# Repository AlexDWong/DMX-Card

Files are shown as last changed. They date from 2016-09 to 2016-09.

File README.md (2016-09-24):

# DMX-Card

Front

## Description
The DMX-Card is a small breakout board that allows developers to quickly add a UART-to-DMX (RS-485) circuit to their designs. It has been designed to cut down on the time spent constructing isolated DMX-512 circuits for prototype designs. The circuit is fully isolated and protected against ESD, and can be easily configured with a 3-pin XLR, 5-pin XLR, or 0.100" connector of the user's choice.

## Updates
**9/24/2016:** Board version 1.1; see directory for changes

**9/22/2016:** Board version 1.0 proven

## Features
* +5V input with polarity and over-current protection
* Full power and data isolation
  * Isolated DC-DC converter (1.5kVDC)
  * Isolated I/O via optocoupler (2.5kVDC)
  * ESD protection on all data inputs and outputs (including DMX)
* Full DMX compliance*
  * ANSI E1.20-2006 RDM compliant circuit, including correct biasing resistors (562/133/562)
  * 10MBd optocouplers
* User-selectable connectors:
  * Output: 
    * Neutrik NC3FAH (3-pin XLR)
    * Neutrik NC5FAH (5-pin XLR)
    * 0.100" PTH connectors (headers, screw terminal blocks, etc.)
  * Input:
    * 0.100" PTH connectors (headers, screw terminal blocks, etc.)

## Physical
* Board Dimensions: 0.95" x 1.90" (24.13mm x 48.26mm) (Actual dimensions will vary depending on the type of output connector installed)
* Board Thickness: 1.6mm
* Input Power: +5VDC, 60mA (nominal)
* Input Connections: +5V, GND, RX, TX, RX/TX Select
* Output: Isolated RS-485/DMX-512 (GND-ISO, D-, D+)
* Mounting: 4x 0.125" holes, located at edges of board

**circuit is constructed to ANSI E1.20; RDM must be correctly implemented on controller for full compliance*

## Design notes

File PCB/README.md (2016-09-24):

# PCB Files

This director contains all the files needed to modify the design of the DMX-Card. Revisions are separated into sub-directories, each of which contain the following files:

* Eagle `.BRD` and `.SCH` files (generated in Eagle 7.6.0)
* Board and schematic `.PNG` files for ease-of-access
* Gerber files
* Bill of Materials

Please note the following:
* All Eagle files have been checked for ERC and DRC errors using rule files provided by Elecrow. **If you choose to use a different fab house, please ensure that the boards meet their DRC requirements.**
* Similarly, the Gerber files have been generated using a CAM file provided by Elecrow; if you are planning to utilize a different fab house, you should either check to ensure they can accept the Gerber files located in this repository or generate your own Gerber files from the Eagle board and schematic files.

## Versions
### Version 1.1
Resolved several issues with version 1.0:
* Mounting holes in V1.0 were placed close to the edge of the board, which resulted in a high probability of edge breakage when depanelizing the boards. As a result, mounting holes have been reworked for greater clearance; note that some holes may be inaccessible depending on the connector choice.
* Input header moved away from the edge of the board to improve screw terminal block support.
* Electrolytic capacitor footprint removed; it was initially included in case additional decoupling was needed, but after testing the existing decoupling is satisfactory.
* Improved SMD component placement for easier hand-soldering. Namely, the two 10uF decoupling capacitors on the isolated side have been spaced further apart from each other, and the SM712 diode has been moved away from R9.
* Improved silkscreen layout to avoid conflicts with pads and vias.

### Version 1.0
Initial release. This version has been tested and is proven to work as described.

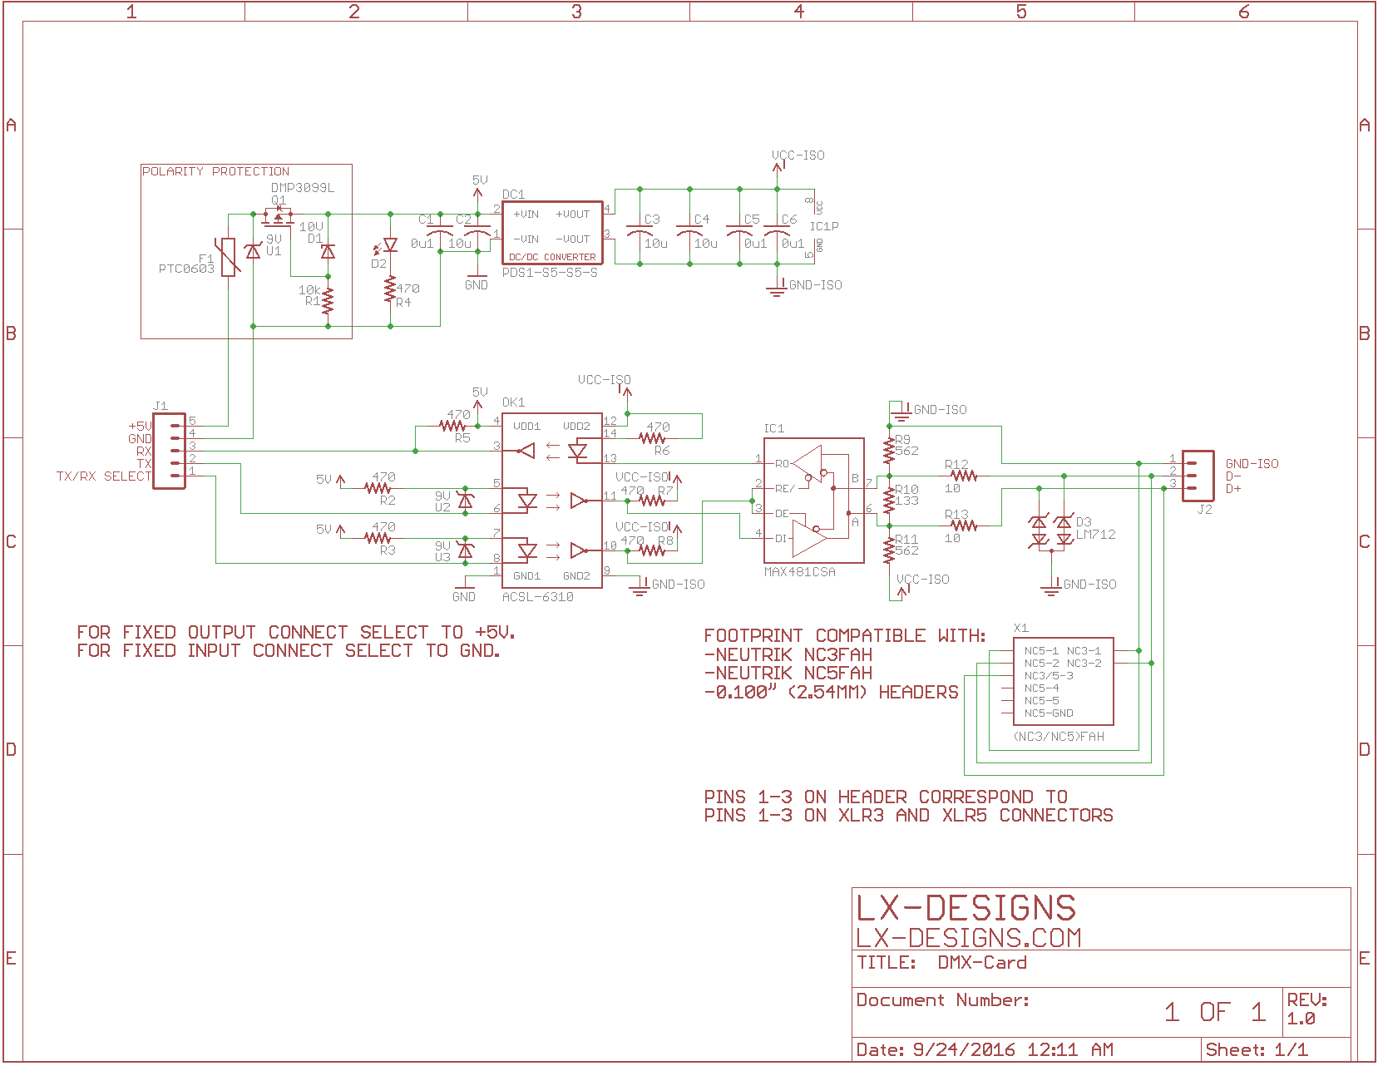
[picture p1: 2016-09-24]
PCB/V1.1/Schematic.png

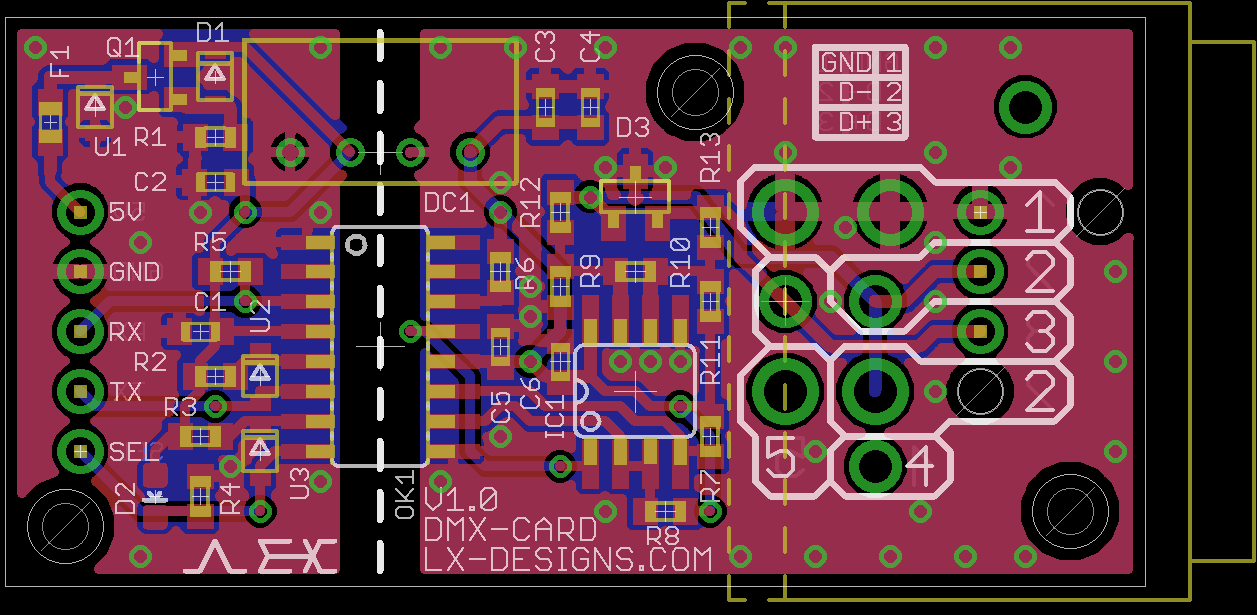
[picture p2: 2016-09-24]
PCB/V1.1/Board.png

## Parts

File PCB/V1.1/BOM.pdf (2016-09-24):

Item | Ref | Qty | Description | Mfg | Part Number
1 | C1, C5, C6 | 3 | Capacitor, 0.1uF, 16V, 10%, 0603 X5R | Murata Electronics | GRM188R61A106KE69D
2 | C2, C3, C4 | 3 | Capacitor, 10uF, 16V, 10%, 0603 X7R | Yageo | CC0603KRX7R7BB104
3 | D1, D4, D5 | 3 | TVS Diode, 1-channel Unidirectional, 9V, SOD323 | Toshiba | DF2S12FU,H3F
4 | D2 | 1 | Zener Diode,7.5V, 2%, 200mW, SOD-323 | ON Semiconductor | MM3Z7V5ST1G
5 | D3 | 1 | LED 2.1V/10mA, 0603 | Lite-On Inc. | LTST-C129GKT
6 | D6 | 1 | TVS Diode, 2-channel bidirectional, 12V/7V, SOT-23 | Littelfuse inc | SM712-02HTG
7 | DC1 | 1 | DC/DC Converter, Isolated, 5V, 1W, SIP-4 | CUI Inc | PDS1-S5-S5-S
8 | F1 | 1 | PTC Fuse, 9V, 200mA/450mA 0603 | Bel Fuse Inc | 0ZCM0020FF2G
9 | IC1 | 1 | Transceiver, RS485, Half-Duplex, 2.5Mbps, SOIC-8 | Maxim Integrated | MAX481CSA+
10 | OK1 | 1 | Optocoupler, 3-channel, 15MBd, SOIC-16 | Broadcom | ACSL-6310-00TE
11 | Q1 | 1 | MOSFET, P-channel, 30V, 65mOhm, SOT-23 | Diodes Incorporated | DMP3099L-7
12 | R1 | 1 | Resistor, 10K, 0.1W, 5%, 0603 | Yageo | RC0603JR-0710KL
13 | R2, R3, R4, R5, R6, R7, R8 | 7 | Resistor, 470, 0.1W, 1%, 0603 | Yageo | RC0603FR-07470RL
14 | R9, R11 | 2 | Resistor, 10K, 0.1W, 5%, 0603 | Yageo | RC0603FR-07562RL
15 | R10 | 1 | Resistor, 133, 0.1W, 1%, 0603 | Yageo | RC0603FR-07133RL
16 | R12, R13 | 2 | Resistor, 10, 0.1W, 1%, 0603 | Yageo | RC0603FR-0710RL
Item | Ref | Qty | Description | Mfg | Part Number
17 | X1 | 1 | Connector, XLR-3, Female, Horizontal PCB | Neutrik | NC3FAH
18 | X2 | 1 | Connector, XLR-5, Female, Horizontal PCB | Neutrik | NC5FAH
19 | J1 | 1 | Connector, Screw Terminal, 5 Position, 150V/10A | TE Connectivity | 282834-5
20 | J2 | 1 | Connector, Screw Terminal, 3 Position, 150V/10A | TE Connectivity | 282834-3

PCB Do Not Populate (User-Discresion)

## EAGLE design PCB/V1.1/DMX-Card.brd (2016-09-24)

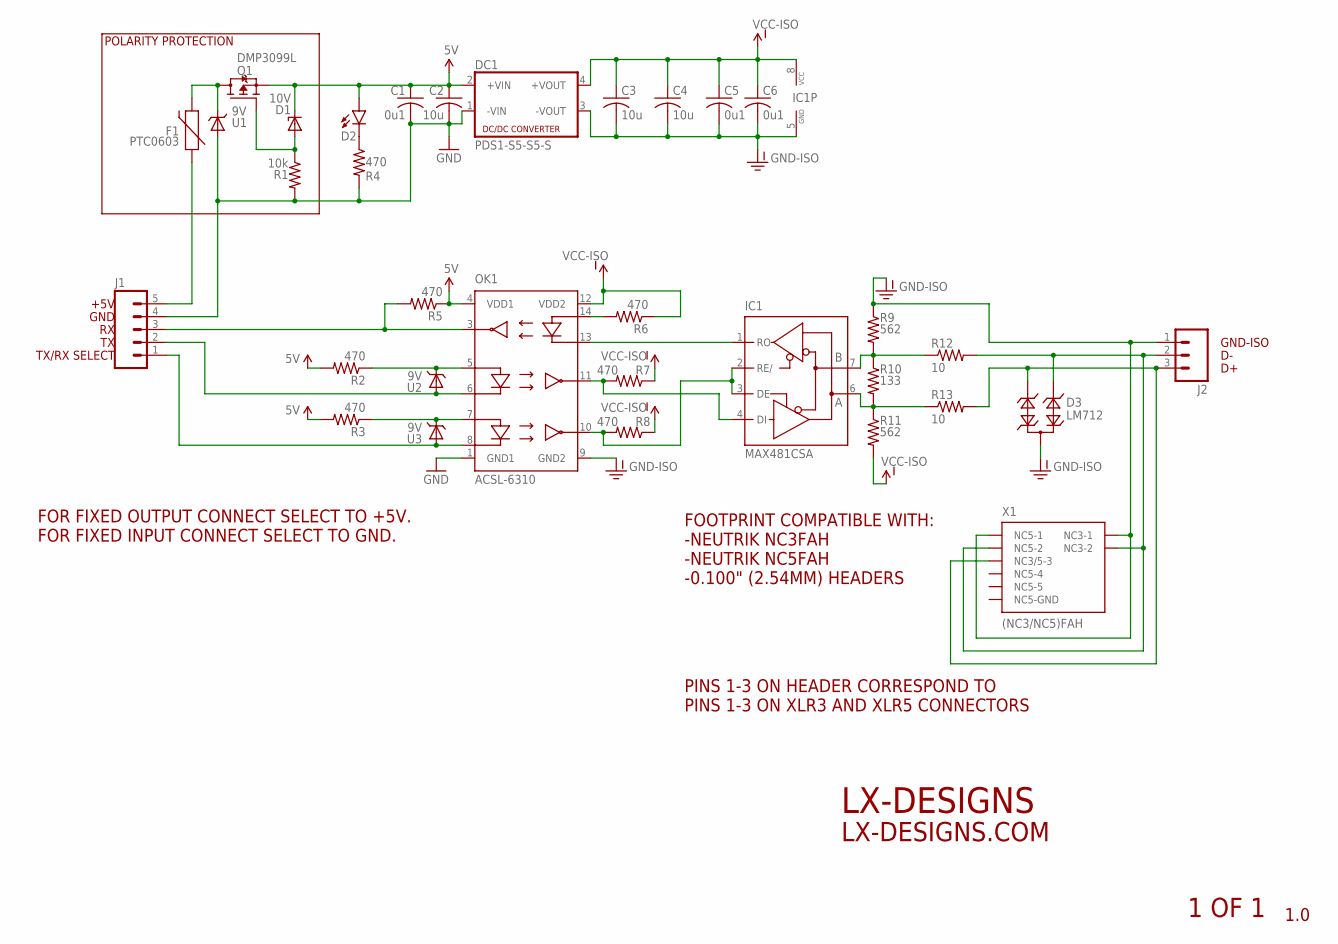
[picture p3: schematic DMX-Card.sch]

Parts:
C1, C5, C6: 0u1; C0603K
C2, C3, C4: 10u; C0603K
D1: 10V; SOD323
D2: LED0603; LED-0603
D3: LM712; SOT23
DC1: PDS1-S5-S5-S; 4SIL
F1: PTC0603; 0603
IC1: MAX481CSA; SO08
J1: M05NO_SILK; 1X05_NO_SILK
J2: M031X03_NO_SILK; 1X03_NO_SILK
OK1: ACSL-6310; SO-16
Q1: DMP3099L; SOT23
R1: 10k; R0603
R2, R3, R4, R5, R6, R7, R8: 470; R0603
R9, R11: 562; R0603
R10: 133; R0603
R12, R13: 10; R0603
U1, U2, U3: 9V; SOD323-NOSILK
X1: (NC3/NC5)FAH; NC3FAH-NC5FAH-NOSILK

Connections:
5V: C1.1, C2.1, D1.C, D2.A, DC1.2 (+VIN), OK1.4 (VDD1), Q1.2 (S), R2.2, R3.2, R5.1
D+: D3.2, J2.3, R13.2, X1.NC3-3 (NC3/5-3)
D-: D3.1, J2.2, R12.2, X1.NC3-2, X1.NC5-2
GND: C1.2, C2.2, DC1.1 (-VIN), J1.4, OK1.1 (GND1), R1.2, R4.2, U1.A
GND-ISO: C3.2, C4.2, C5.2, C6.2, D3.3, DC1.3 (-VOUT), IC1.5 (GND), J2.1, OK1.9 (GND2), R9.1, X1.NC3-1, X1.NC5-1
unnamed: IC1.7 (B), R9.2, R10.1, R12.1
unnamed: IC1.6 (A), R10.2, R11.1, R13.1
unnamed: F1.1, J1.5
unnamed: D2.C, R4.1
unnamed: IC1.1 (RO), OK1.13 (C3)
unnamed: OK1.5 (A1), R2.1, U2.C
unnamed: OK1.14 (A3), R6.2
unnamed: J1.3, OK1.3 (V03), R5.2
unnamed: IC1.4 (DI), OK1.11 (VO1), R7.2
unnamed: OK1.7 (A2), R3.1, U3.C
unnamed: J1.2, OK1.6 (C1), U2.A
unnamed: F1.2, Q1.3 (D), U1.C
unnamed: J1.1, OK1.8 (C2), U3.A
unnamed: D1.A, Q1.1 (G), R1.1
OPTO-OUT: IC1.2 (RE/), IC1.3 (DE), OK1.10 (VO2), R8.2
VCC-ISO: C3.1, C4.1, C5.1, C6.1, DC1.4 (+VOUT), IC1.8 (VCC), OK1.12 (VDD2), R6.1, R7.1, R8.1, R11.2

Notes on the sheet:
+5V
GND
TX/RX SELECT
PINS 1-3 ON HEADER CORRESPOND TO PINS 1-3 ON XLR3 AND XLR5 CONNECTORS
GND-ISO
FOR FIXED OUTPUT CONNECT SELECT TO +5V. FOR FIXED INPUT CONNECT SELECT TO GND.
1.0
LX-DESIGNS
POLARITY PROTECTION
FOOTPRINT COMPATIBLE WITH: -NEUTRIK NC3FAH -NEUTRIK NC5FAH -0.100" (2.54MM) HEADERS
LX-DESIGNS.COM
1 OF 1

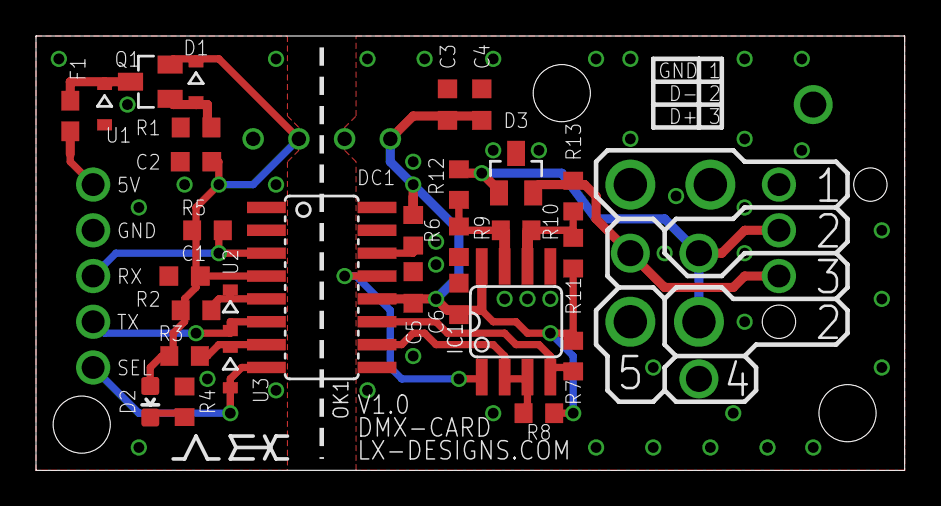
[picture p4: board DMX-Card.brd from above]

Board: 2 copper layers, 48.3 x 24.1 mm, 33 parts (0 on the bottom side), 21 nets.

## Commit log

2016-09-13 [UNPROVEN] PCB version 1.0
    [DMX-Card.brd, DMX-Card.sch]
2016-09-13 update gerbers
2016-09-17 Update BOM
    [DMX-Card.brd, DMX-Card.sch]
2016-09-22 PCB images
2016-09-24 Revision 1.1
    [DMX-Card.brd, DMX-Card.sch]

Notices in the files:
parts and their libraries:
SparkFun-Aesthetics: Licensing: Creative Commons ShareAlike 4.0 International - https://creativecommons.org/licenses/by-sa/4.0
